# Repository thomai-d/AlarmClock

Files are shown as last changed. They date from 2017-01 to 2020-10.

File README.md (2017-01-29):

# AlarmClock
Arduino based alarm clock with wake up light

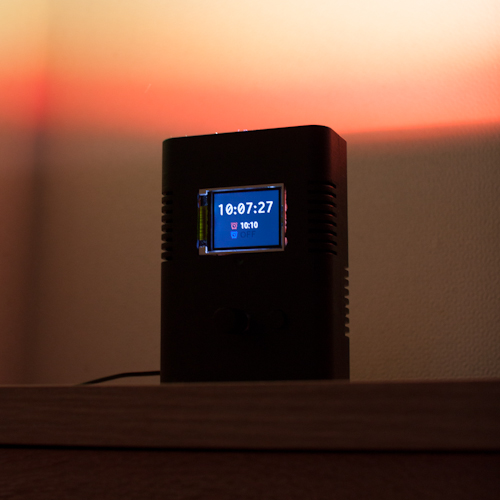
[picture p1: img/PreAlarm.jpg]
WakeUpLight


## Features
* Two individually configurable alarm times
* 15 minutes before alarm, the power-LED is slowly ramped on
* LED wake up color is configurable by the user
* Slowly rising acoustic alarm
* Temperature and air pressure trend for the last 8 hours
* Display brightness is automatically reduced in the dark (LDR)
* Power fail safe (battery buffered RTC)

## Hardware
* atmega328 @ 16MHz
* 2.8" SPI TFT Screen (320x240) with ILI9331 controller
* DS3231 battery buffered RTC with I2C interface
* BMP180 temperature / pressure sensor with I2C interface
* High Power RGB-LED (~4.5W)
* Eagle files / part list included

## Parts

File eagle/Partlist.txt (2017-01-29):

Partlist

Exported from AlarmClock.sch at 08.12.2016 19:17

EAGLE Version 7.6.0 Copyright (c) 1988-2016 CadSoft

Assembly variant: 

Part         Value           Device                       Package               Library                    Sheet

BMP180                       PINHD-1X4                    1X04                  pinhead                    1
C1           100n            C-EUC0805                    C0805                 resistor                   1
C2           22p             C-EUC0805                    C0805                 resistor                   1
C3           22p             C-EUC0805                    C0805                 resistor                   1
C4           47n             C-EUC0805                    C0805                 resistor                   1
C5           100n            C-EUC0805                    C0805                 resistor                   1
C6           100n            C-EUC0805                    C0805                 resistor                   1
C7           100µ            CPOL-EUF                     PANASONIC_F           resistor                   1
CON-BUTTON-0                 PINHD-1X2/90                 1X02/90               pinhead                    1
CON-BUTTON-2                 PINHD-1X2/90                 1X02/90               pinhead                    1
CON-ROTARY                   PINHD-1X4/90                 1X04/90               pinhead                    1
FTDI-POWER                   PINHD-1X2                    1X02                  pinhead                    1
J2           FTDI_DEVICE     FTDI_DEVICE                  FTDI_DEVICE_SIDE      SparkFun-Connectors        1
LDR                          PINHD-1X2                    1X02                  pinhead                    1
LED                          PINHD-1X4                    1X04                  pinhead                    1
POWER                        PINHD-1X2                    1X02                  pinhead                    1
Q1           16MHZ           CRYSTALHC49UP                HC49UP                crystal                    1
Q2           2n7000          MOSFET-NCHANNEL2N7000        TO-92                 SparkFun-DiscreteSemi      1
Q3           2n7000          MOSFET-NCHANNEL2N7000        TO-92                 SparkFun-DiscreteSemi      1
Q4           2n7000          MOSFET-NCHANNEL2N7000        TO-92                 SparkFun-DiscreteSemi      1
R1           10k             R-EU_M0805                   M0805                 resistor                   1
R2           15/2W           R-EU_0414/15                 0414/15               resistor                   1
R3           15/2W           R-EU_0414/15                 0414/15               resistor                   1
R4           15/2W           R-EU_0414/15                 0414/15               resistor                   1
R5           100k            R-EU_M0805                   M0805                 resistor                   1
R6           100k            R-EU_M0805                   M0805                 resistor                   1
R7           100k            R-EU_M0805                   M0805                 resistor                   1
R8           10k             R-EU_R0805                   R0805                 resistor                   1
RTC                          PINHD-1X4                    1X04                  pinhead                    1
SG1          BUZZERPTH       BUZZERPTH                    BUZZER-12MM           SparkFun-Electromechanical 1
SPI                          AVR_SPI_PRG_6NS              2X3-NS                SparkFun-Connectors        1
SW-RST                       SWITCH-MOMENTARY-2SMD-1101NE TACTILE-SWITCH-1101NE SparkFun-Electromechanical 1
TFT                          PINHD-1X8                    1X08                  pinhead                    1
U1           ATMEGA328P_TQFP ATMEGA328P_TQFP              TQFP32-08             SparkFun-DigitalIC         1

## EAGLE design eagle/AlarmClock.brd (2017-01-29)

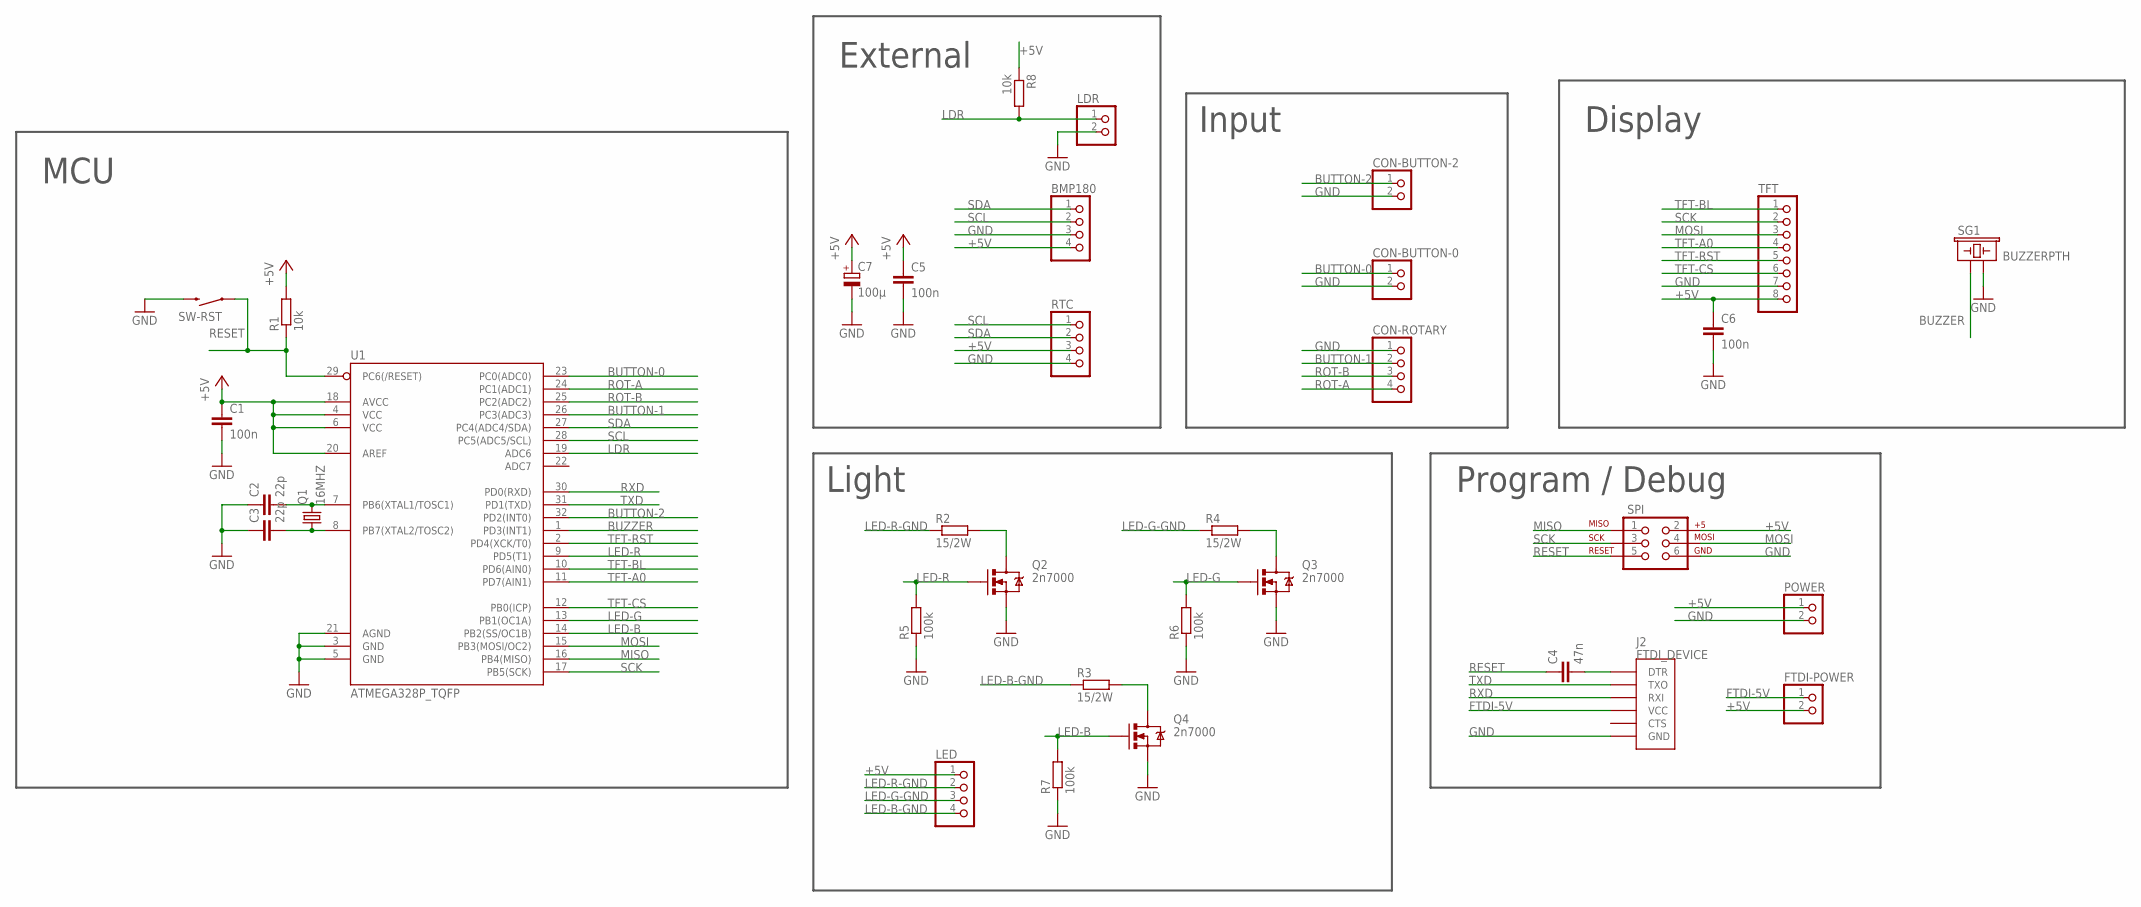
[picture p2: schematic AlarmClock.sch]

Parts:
BMP180: 1X04
C1, C5, C6: 100n; C0805
C2, C3: 22p; C0805
C4: 47n; C0805
C7: 100µ; PANASONIC_F
CON-BUTTON-0, CON-BUTTON-2: 1X02/90
CON-ROTARY: 1X04/90
FTDI-POWER: 1X02
J2: FTDI_DEVICE; FTDI_DEVICE_SIDE
LDR: 1X02
LED: 1X04
POWER: 1X02
Q1: 16MHZ; HC49UP
Q2, Q3, Q4: 2n7000; TO-92
R1: 10k; M0805
R2, R3, R4: 15/2W; 0414/15
R5, R6, R7: 100k; M0805
R8: 10k; R0805
RTC: 1X04
SG1: BUZZERPTH; BUZZER-12MM
SPI: AVR_SPI_PRG_6NS; 2X3-NS
SW-RST: SWITCH-MOMENTARY-2SMD-1101NE; TACTILE-SWITCH-1101NE
TFT: 1X08
U1: ATMEGA328P_TQFP; TQFP32-08

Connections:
+5V: BMP180.4, C1.1, C5.1, C6.1, C7.+, FTDI-POWER.2, LED.1, POWER.1, R1.2, R8.1, RTC.3, SPI.2, TFT.8, U1.4 (VCC), U1.6 (VCC), U1.18 (AVCC), U1.20 (AREF)
BUTTON-0: CON-BUTTON-0.1, U1.23 (PC0(ADC0))
BUTTON-1: CON-ROTARY.2, U1.26 (PC3(ADC3))
BUTTON-2: CON-BUTTON-2.1, U1.32 (PD2(INT0))
BUZZER: SG1.+ (1), U1.1 (PD3(INT1))
FTDI-5V: FTDI-POWER.1, J2.P$4 (VCC)
GND: BMP180.3, C1.2, C2.1, C3.1, C5.2, C6.2, C7.-, CON-BUTTON-0.2, CON-BUTTON-2.2, CON-ROTARY.1, J2.P$6 (GND), LDR.2, POWER.2, Q2.1 (S), Q3.1 (S), Q4.1 (S), R5.1, R6.1, R7.1, RTC.4, SG1.- (2), SPI.6, SW-RST.2, TFT.7, U1.3 (GND), U1.5 (GND), U1.21 (AGND)
LDR: LDR.1, R8.2, U1.19 (ADC6)
LED-B: Q4.2 (G), R7.2, U1.14 (PB2(SS/OC1B))
LED-B-GND: LED.4, R3.1
LED-G: Q3.2 (G), R6.2, U1.13 (PB1(OC1A))
LED-G-GND: LED.3, R4.1
LED-R: Q2.2 (G), R5.2, U1.9 (PD5(T1))
LED-R-GND: LED.2, R2.1
MISO: SPI.1, U1.16 (PB4(MISO))
MOSI: SPI.4, TFT.3, U1.15 (PB3(MOSI/OC2))
unnamed: C4.2, J2.P$1 (DTR)
unnamed: C2.2, Q1.2, U1.7 (PB6(XTAL1/TOSC1))
unnamed: C3.2, Q1.1, U1.8 (PB7(XTAL2/TOSC2))
unnamed: Q2.3 (D), R2.2
unnamed: Q3.3 (D), R4.2
unnamed: Q4.3 (D), R3.2
RESET: C4.1, R1.1, SPI.5, SW-RST.1, U1.29 (PC6(/RESET))
ROT-A: CON-ROTARY.4, U1.24 (PC1(ADC1))
ROT-B: CON-ROTARY.3, U1.25 (PC2(ADC2))
RXD: J2.P$3 (RXI), U1.30 (PD0(RXD))
SCK: SPI.3, TFT.2, U1.17 (PB5(SCK))
SCL: BMP180.2, RTC.1, U1.28 (PC5(ADC5/SCL))
SDA: BMP180.1, RTC.2, U1.27 (PC4(ADC4/SDA))
TFT-A0: TFT.4, U1.11 (PD7(AIN1))
TFT-BL: TFT.1, U1.10 (PD6(AIN0))
TFT-CS: TFT.6, U1.12 (PB0(ICP))
TFT-RST: TFT.5, U1.2 (PD4(XCK/T0))
TXD: J2.P$2 (TXO), U1.31 (PD1(TXD))

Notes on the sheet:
External
Input
Light
Program / Debug
Display
MCU

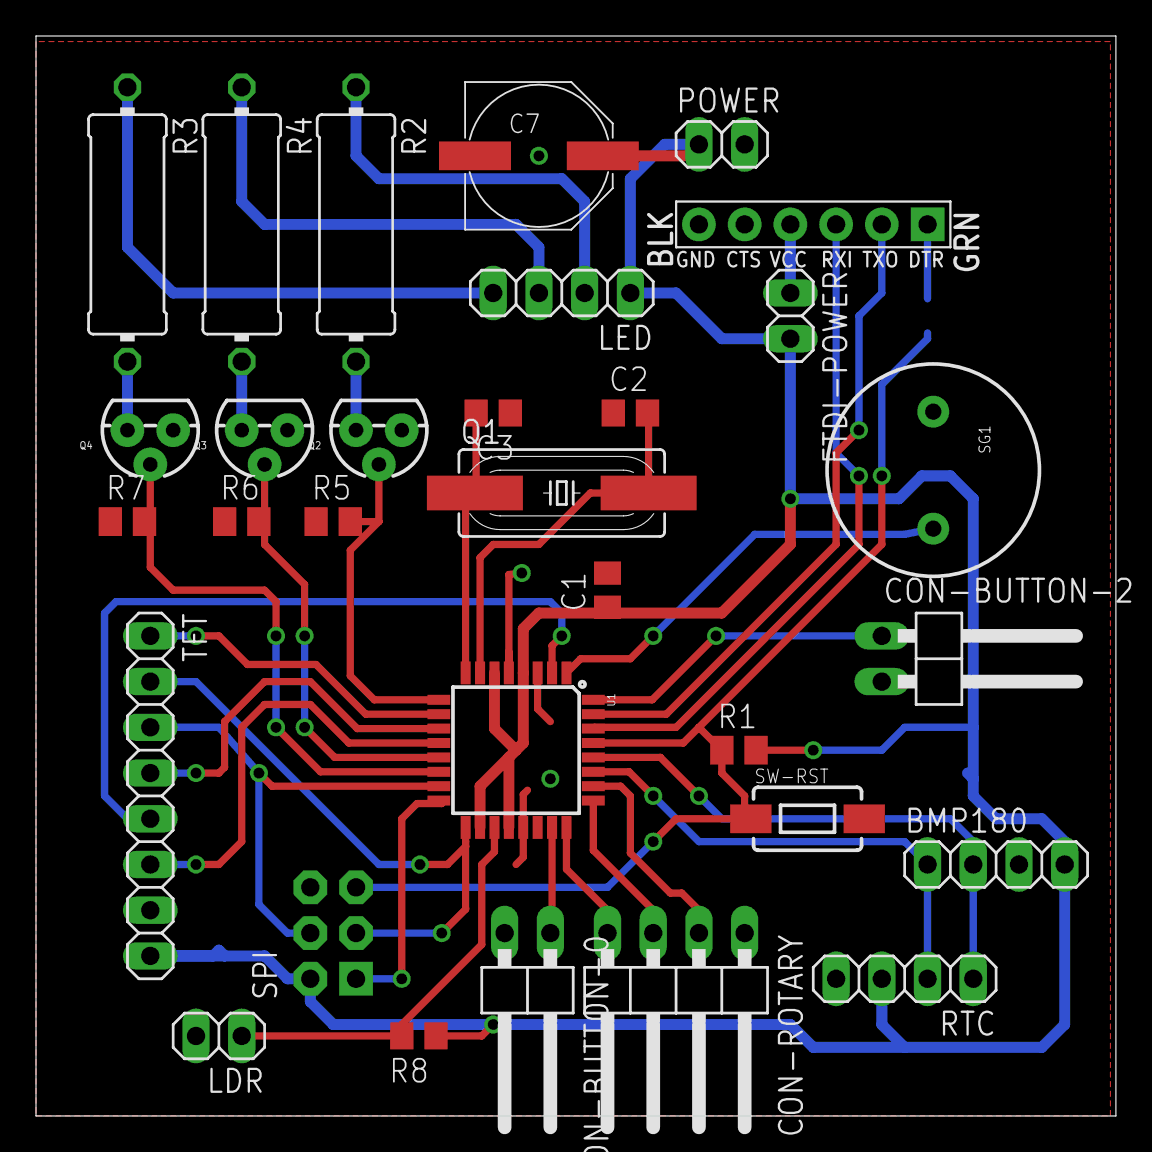
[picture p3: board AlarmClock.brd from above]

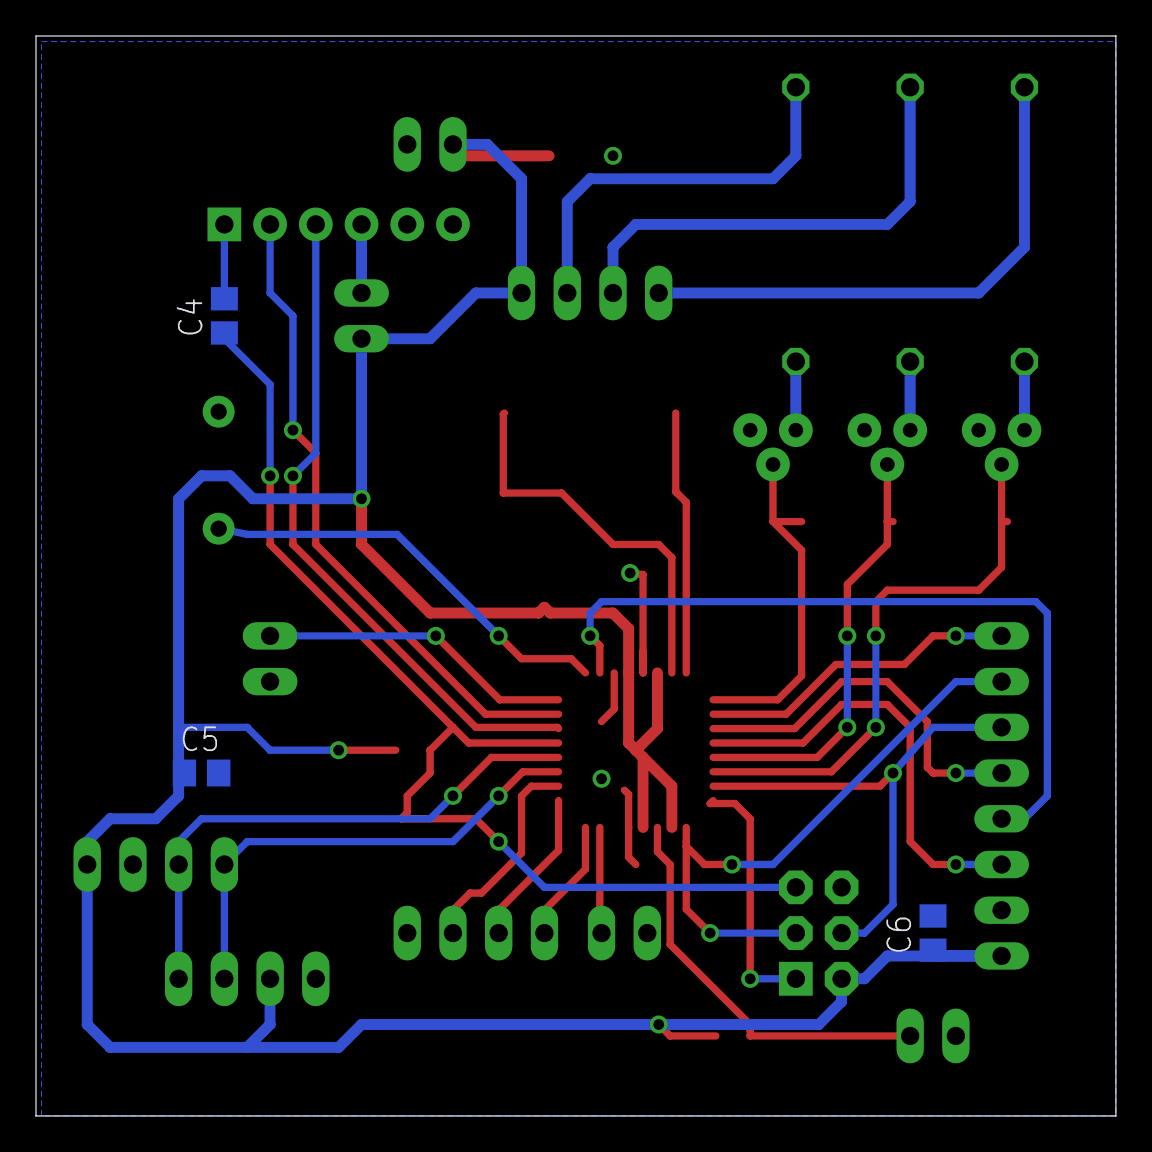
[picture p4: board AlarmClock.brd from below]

Board: 2 copper layers, 60.0 x 60.0 mm, 34 parts (3 on the bottom side), 34 nets.

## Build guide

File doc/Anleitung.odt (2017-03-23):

Anzeige

Durch Drücken des Menüknopfes schaltet sich die Hintergrundbeleuchtung ein.

Die Anzeigehelligkeit passt sich automatisch an das Umgebungslicht an (Photosensor).

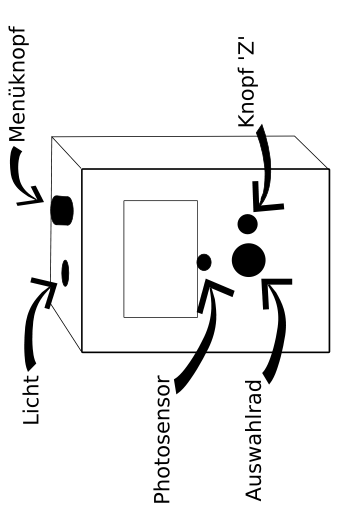
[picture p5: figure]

Alarm einstellen

In der Uhrzeitanzeige kann durch Drücken des Auswahlrades durch zwei unabhängige Weckzeiten geschalten werden. Durch Drehen des Auswahlrades lässt sich die durch einen Stift hervorgehobene Weckzeit anpassen oder durch Drücken der Taste „Z“ deaktivieren.

Alarm

15min vor dem Wecken wird die Helligkeit der LED langsam erhöht, bis letztendlich der Alarm zur eingestellten Weckzeit ertönt. Nach einer Minute wird der Alarm automatisch beendet, sofern er nicht vorher über den Menüknopf quittiert wird.

Eine Schlummerfunktion ist nicht vorgesehen. Wenn der Wecker klingelt, ist es Zeit aufzustehen. Punkt.

Trend

Durch erneutes Drücken des Menüknopfes gelangt man zum Wettertrend der letzten 8 Stunden. Oben wird die Temperatur angezeigt (in °C), unten der Luftdruck (in kPa).

Es wird der Absolutdruck angezeigt, nicht der Druck auf Meereshöhe.

Strom

Der Wecker verfügt über eine interne Batterie. Das bedeutet, dass die Uhrzeit auch ohne eingestecktes Netzteil eine gewisse Zeit lang korrekt weiterläuft. Ein Stromausfall (sofern er nicht genau in der Weckminute stattfindet) hat also keinen Einfluss auf die Funktion des Weckers.

Der Stromverbrauch liegt zwischen <1W (Standby) und 4W (Wecken mit 100% Licht).

Datum/Uhrzeit einstellen

Die Einstellungsseite wird geöffnet, indem im Trend gleichzeitig „Knopf Z“ und anschließend der Menükopf gedrückt wird. Datum und Uhrzeit lassen sich wie die Alarmzeit über das Auswahlrad einstellen. Ist auch das Datum korrekt eingestellt, erfolgt die Umstellung der Sommer-/Winterzeit automatisch.

Lichtfarbe einstellen

Auf der Einstellungsseite lässt sich auch die Farbe der Weck-LED durch zwei Werte, die Farbton und Sättigungswert im HSV-Farbkreis repräsentieren einstellen.

Rot (0°) aktiviert Stoffwechsel und Immunsystem, aber auch die Sexualität.

Grün (120°) wirkt beruhigend und erfrischend und fördert die Kreativität.

Blau (240°) erfrischt, wirkt beruhigend und fördert die Konzentration.

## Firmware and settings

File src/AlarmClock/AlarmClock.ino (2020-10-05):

#include <Wire.h>
#include <ucglib.h>
#include <TimeLib.h>
#include <EEPROM.h>
#include <DS3232RTC.h>
#include <Adafruit_BMP085.h>
#include <avr/wdt.h>
#include <color.h>

#include "Page.h"
#include "MainPage.h"
#include "ConfigPage.h"
#include "InputHardware.h"
#include "PinDefinitions.h"
#include "PageManager.h"
#include "UserActivityManager.h"
#include "TrendPage.h"
#include "TrendData.h"
#include "DateTime.h"
#include "Debug.h"

MainPage mainPage;
TrendPage trendPage;
ConfigPage configPage;

void setup() 
{
	Serial.begin(115200);
	Serial.println(F("AlarmClock"));
	delay(50);

	// Initialize watchdog.
	wdt_enable(WDTO_4S);

	// Initialize RTC.
	DateTime.Initialize();

	// Init display.
	Display2.Initialize();

	// Initialize stuff.
	AlarmManager.ReloadAlarms();
	InputHardware.Initialize();
	TrendData.Initialize();

	// Speaker test.
	OutputHardware.AlarmTest();

	// Initialize pages.
	PageManager.SetPage(0, &mainPage);
	PageManager.SetPage(1, &trendPage);
	PageManager.SetPage(2, &configPage);
	PageManager.Home();

	// Setup Timer2 (16ms)
	TCCR2A = 0;
	TCCR2B = 7;
	bitSet(TIMSK2, TOIE2);
}

void loop() 
{
	// Time can be synchronized from Serial.
	if (Serial.available())
	{
		if (Serial.peek() == 'T')
			DateTime.SyncFromSerial();
		else if (Serial.peek() == '!')
		{
			if (Serial.find("!Reset"))
			{
				AlarmManager.FactoryReset();
				Serial.println("Factory reset.");
			}
		}
	}
	
	AlarmManager.Service();
	TrendData.Service();
	UserActivityManager.Service();

	PageManager.Service();

	wdt_reset();
}

void OnButton2Down()
{
	if (AlarmManager.IsAlarmActive())
	{
		// Quit pending alarms.
		AlarmManager.QuitFirstAlarm();
	}
	else if (!Display2.IsBacklightOn())
	{
		// Wakeup.
		PageManager.Home();
	}
	else
	{
		// Next page.
		PageManager.NextPage();
	}
}

void OnAlarmActivated()
{
	PageManager.Home();
}

ISR(TIMER2_OVF_vect)
{
	cli();

	OutputHardware.OnTimer2Tick();
	Display2.OnTimer2Tick();

	sei();
}

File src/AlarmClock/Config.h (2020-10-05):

#ifndef CONFIG_H
#define CONFIG_H

//#define DEBUG

/* WORKAROUNDS */

#define ALTERNATIVE_BUTTONS	// for #1
#define ALTERNATIVE_ROTARY	// #1, #4, #5
//#define ALTERNATIVE_LDR		// #3
#define NO_LDR				// #1

/* FONTS */

#define FONT_BIG24	ucg_font_inr24_mn
#define FONT_MED14	ucg_font_helvR14_hr
#define FONT_TINY4	ucg_font_04b_03b_hn

#define BUTTON_DEBOUNCE_MS					100			// Pushbutton debounce time [ms].


/* BEHAVIOR */

#define USER_INACTIVITY_TIMEOUT_NORMAL		10			// Inactivity timeout for main page [s].
#define USER_INACTIVITY_TIMEOUT_INPUT		25			// Inactivity timeout when editing stuff [s].
#define USER_INACTIVITY_TIMEOUT_TREND		30			// Inactivity timeout when viewing trend [s].
#define USER_INACTIVITY_TIMEOUT_SETTINGS	60			// Inactivity timeout when viewing settings [s].

/* ALARM */

#define ALARM_STEPS_MINUTES					5			// Alarm change step [min].
#define ALARM_RAMP_SECONDS					15 * 60		// Time the light goes on before the alarm sound [s].

/* TREND */

#define TREND_PRESSURE_MIN					97			// Minumum pressure displayed by the trend [kPa].
#define TREND_PRESSURE_MAX					104			// Maximum pressure displayed by the trend [kPa].
#define TREND_PRESSURE_STEP					1			// Pressure grid line distance [kPa].

#define TREND_TEMP_MIN						14			// Minimum temperature displayed by the trend [°C].
#define TREND_TEMP_MAX						28			// Maximum temperature displayed by the trend [°C].
#define TREND_TEMP_STEP						2			// Temperature grid line distance [°K].

#define MINUTE_MS							60000			
#define SAMPLE_TIME_MS						5 * MINUTE_MS	// Delay between trend samples [ms].
#define TREND_MAX_ITEMS						100				// Trend maximum items.

/* DISPLAY */

#define LIGHT_SAMPLES				8					// Number of samples for averaging available light.
#define BACKLIGHT_MIN_LEVEL			3 					// Minimum backlight brighness.
#define BACKLIGHT_MAX_LEVEL			100 				// Maximum backlight brighness.
#define LED_ON_INTENSITY			255					// Intensity of LED light when manually activated.

// EEPROM Adresses
#define EEPROM_ALARM0_H		0
#define EEPROM_ALARM0_M		1
#define EEPROM_ALARM0_ON	2	
#define EEPROM_ALARM1_H		3
#define EEPROM_ALARM1_M		4
#define EEPROM_ALARM1_ON	5	
#define EEPROM_HUE			6				// Hue, [10°]
#define EEPROM_SAT			7				// Saturation, [1/10]


#endif

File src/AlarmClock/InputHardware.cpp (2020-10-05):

#include "InputHardware.h"

const uint8_t InputHardwareClass::lookupTable[7][4] = {
	{ R_START,    R_CW_BEGIN,  R_CCW_BEGIN, R_START },
	{ R_CW_NEXT,  R_START,     R_CW_FINAL,  R_START | DIR_CW },
	{ R_CW_NEXT,  R_CW_BEGIN,  R_START,     R_START },
	{ R_CW_NEXT,  R_CW_BEGIN,  R_CW_FINAL,  R_START },
	{ R_CCW_NEXT, R_START,     R_CCW_BEGIN, R_START },
	{ R_CCW_NEXT, R_CCW_FINAL, R_START,     R_START | DIR_CCW },
	{ R_CCW_NEXT, R_CCW_FINAL, R_CCW_BEGIN, R_START }
};

InputHardwareClass::InputHardwareClass()
{
	cli();

	// Setup pins.
	DDRC &= !(_BV(DDC0) | _BV(DDC1) | _BV(DDC2) | _BV(DDC3));
	PORTC |= _BV(PC0) | _BV(PC1) | _BV(PC2) | _BV(PC3);
	pinMode(DI_BUTTON2, INPUT_PULLUP);

	// Setup PCINT.
	PCICR |= _BV(PCIE1);		// Enable PCINT1
	PCIFR |= _BV(PCIF1);		// Clear pending PCINT1
	PCMSK1 |= _BV(PCINT8)		// Enable pins.
		| _BV(PCINT9)
		| _BV(PCINT10)
		| _BV(PCINT11);

	// Setup INT0.
	bitClear(EICRA, ISC00);		// Configure INT0 on
	bitSet(EICRA, ISC01);		// Falling edge.
	bitSet(EIMSK, INT0);		// Enable interrupt.

	sei();
}

void InputHardwareClass::Initialize()
{
	UserActivityManager.ReportUserActivity();
}

void InputHardwareClass::OnINT0()
{
	cli();

	if (this->blockModeButton)
		return;

	uint32_t timeMs = millis();
	uint32_t delta = timeMs - b2_lastEvent;
	if (delta > BUTTON_DEBOUNCE_MS)
	{
		OnButton2Down();

		this->b2_lastEvent = timeMs;
		UserActivityManager.ReportUserActivity();
	}

	sei();
}

uint8_t InputHardwareClass::ReadBrightness()
{
#ifdef NO_LDR
	return 240;
#else
	return analogRead(AI_LDR) >> 2;
#endif
}

void InputHardwareClass::OnPCINT1()
{
	cli();
	
	uint8_t pinc = PINC;

	// Check buttons.
	bool b0wasUp = bitRead(button_states, BUTTON0_BIT);
	bool b1wasUp = bitRead(button_states, BUTTON1_BIT);
	bool b0isUp = bitRead(pinc, BUTTON0_BIT);
	bool b1isUp = bitRead(pinc, BUTTON1_BIT);

	bool b0Changed = b0wasUp != b0isUp;
	bool b1Changed = b1wasUp != b1isUp;
	if (b0Changed || b1Changed)
	{
		uint32_t timeMs = millis();
		UserActivityManager.ReportUserActivity();

		if (b0Changed)
		{
			uint32_t delta = timeMs - b0_lastEvent;
			if (delta > BUTTON_DEBOUNCE_MS)
			{
				if (Focus && !blockInput)
				{
					if (b0isUp)
					{
						Focus->OnButton0Up(delta);
					}
					else
					{
						Focus->OnButton0Down();
					}
				}

				b0_lastEvent = timeMs;
				bitWrite(button_states, BUTTON0_BIT, b0isUp);
			}
		}

		if (b1Changed)
		{
			uint32_t delta = timeMs - b1_lastEvent;
			if (delta > BUTTON_DEBOUNCE_MS)
			{
				if (Focus && (!blockInput || Focus->ForceReceiveButton1()))
				{
					if (b1isUp)
					{
						Focus->OnButton1Up(delta);
					}
					else
					{
						Focus->OnButton1Down();
					}
				}

				b1_lastEvent = timeMs;
				bitWrite(button_states, BUTTON1_BIT, b1isUp);
			}
		}

		sei();
	}

	
	// Check rotary.
	rotary_state = lookupTable[rotary_state & 0xf][(pinc >> 1) & 3];

	if (Focus && !blockInput)
	{
		UserActivityManager.ReportUserActivity();

		switch (rotary_state & 0x30)
		{
		case DIR_CW:
#ifdef ALTERNATIVE_ROTARY
			Focus->OnRotaryChanged(-1);
#else
			Focus->OnRotaryChanged(+1);
#endif
			break;

		case DIR_CCW:
#ifdef ALTERNATIVE_ROTARY
			Focus->OnRotaryChanged(+1);
#else
			Focus->OnRotaryChanged(-1);
#endif
			break;
		}
	}
}

ISR(PCINT1_vect)
{
	cli();
	InputHardware.OnPCINT1();
	sei();
}

ISR(INT0_vect)
{
	cli();
	InputHardware.OnINT0();
	sei();
}

InputHardwareClass InputHardware;

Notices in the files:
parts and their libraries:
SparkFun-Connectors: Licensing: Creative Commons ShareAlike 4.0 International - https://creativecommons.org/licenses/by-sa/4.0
